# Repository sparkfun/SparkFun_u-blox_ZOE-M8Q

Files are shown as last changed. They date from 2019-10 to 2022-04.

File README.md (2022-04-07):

SparkFun u-blox ZOE-M8Q
========================================

SparkFun u-blox ZOE-M8Q (https://www.sparkfun.com/products/15193)

[*SparkFun u-blox ZOE-M8Q (GPS-15193)*](https://www.sparkfun.com/products/15193)

The ZOE-M8Q is a high quality GPS with equally impressive configurability.  We broke out the basic pins and added all the supporting circuitry to make this module even easier to use.  

Repository Contents
-------------------

* **/Documentation** - Data sheets, additional product information
* **/Hardware** - Eagle design files (.brd, .sch)
* **/Production** - Production panel files (.brd)

Documentation
--------------
* **[Installing an Arduino Library Guide](https://learn.sparkfun.com/tutorials/installing-an-arduino-library)** - Basic information on how to install an Arduino library.
* **[Library](https://github.com/sparkfun/SparkFun_u-blox_GNSS_Arduino_Library)** - Arduino Library used with the SparkFun ZOE-M8Q 
* **[Hookup Guide](https://learn.sparkfun.com/tutorials/sparkfun-gps-breakout-zoe-m8q-and-sam-m8q-hookup-guide)** - Basic hookup guide for the SparkFun ZOE-M8Q.

License Information
-------------------

This product is _**open source**_! 

Please review the LICENSE.md file for license information. 

If you have any questions or concerns on licensing, please contact technical support on our [SparkFun forums](https://forum.sparkfun.com/viewforum.php?f=152).

Distributed as-is; no warranty is given.

- Your friends at SparkFun.

_<COLLABORATION CREDIT>_

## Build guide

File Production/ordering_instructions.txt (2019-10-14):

panel size, 117x117mm
PCB thickness, 0.8mm
number of layers, 2
soldermask color, Red
silkscreen color, White
oz copper, 1oz
finish, HASL lead free
stencils, top+bottom
pcs per panel, 16
min trace width, 0.203200mm / 0.008000in
min drill size, 0.203200mm / 0.008000in

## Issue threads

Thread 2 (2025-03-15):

Confirmation of the ZOE-M8Q PPS pulse accuracy - using the SparkFun GNSSDO

PaulZC, 2025-03-15:
A customer has observed [unusual stability of the ZOE-M8Q PPS signal](https://community.sparkfun.com/t/the-configuration-of-zoe-m8q-cannot-be-permanently-saved-request-to-provide-the-latest-firmware/63843/9).

To investigate, we used the [SparkFun GNSS Disciplined Oscillator](https://www.sparkfun.com/sparkpnt-gnss-disciplined-oscillator.html) to confirm the accuracy of the PPS signal.

## Setup

[ZOE-M8Q Breakout](https://www.sparkfun.com/sparkfun-gps-breakout-zoe-m8q-qwiic.html)
3.3V power is provided via an FTDI interface cable, linking the breakout to a PC
The u.FL connector is connected to an active L1 GPS antenna with a partial (~60%) view of the sky

[SparkFun GNSSDO](https://www.sparkfun.com/sparkpnt-gnss-disciplined-oscillator.html)
Power is provided by Power-over-Ethernet
The GNSSDO has an active Fugro AtomiChron subscription
The quoted event accuracy of the mosaic-T is better than 20ns
The GNSS SMA connector is connected to an active [L1/L2/L5 antenna](https://www.sparkfun.com/gnss-multi-band-l1-l2-l5-surveying-antenna-tnc-spk6618h.html) with a good view of the sky

The ZOE PPS signal is connected to the GNSSDO EVENT_A SMA input (center pin)
ZOE GND is connected to GNSSDO GND at the EVENT_A SMA input

The [RxTools](https://www.septentrio.com/en/products/gps-gnss-receiver-software/rxtools) RxControl Expert Console ExEvent window was used to record the timing of the PPS signal. The connection was TCP/IP over Ethernet.

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

## Expected PPS Accuracy

The ZOE-M8Q datasheet quotes the accuracy of time pulse signal as better than: 30ns RMS, 60ns 99%

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

## Measured Accuracy

The ExEvent messages were logged for 1646 seconds
The ExEvent Rx TOW timestamps were extracted and converted to CSV
A simple pivot table was used to analyze the offset of the PPS events

The full CSV data is available on a [Google Sheet](https://docs.google.com/spreadsheets/d/1XdMT7Z7D9bLWwuqtR6gXf69PPPQHZF1jfgT-jtaXLxE/edit?usp=sharing)

Only five discrete pulse offsets were observed: 17ns minimum, 84ns maximum, 49.94ns was recorded for 1458 out of 1646 seconds

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

## Conclusion

We can not replicate the excessive (microsecond) pulse offsets observed by the Original Poster. The ZOE-M8Q PPS pulses appear to be completely within specification.

Closed 2025-03-15.

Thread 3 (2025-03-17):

Module configuration reverts to defaults after power outage

PaulZC, 2025-03-17:
A customer has observed that the [ZOE-M8Q reverts to the default configuration after a power outage of a few hours](https://community.sparkfun.com/t/the-configuration-of-zoe-m8q-cannot-be-permanently-saved-request-to-provide-the-latest-firmware/63843).

To replicate:

## Setup

[ZOE-M8Q Breakout](https://www.sparkfun.com/sparkfun-gps-breakout-zoe-m8q-qwiic.html)
3.3V power is provided via an FTDI interface cable, linking the breakout to a PC
The u.FL connector is connected to an active L1 GPS antenna with a partial (~60%) view of the sky

With the 3.3V FTDI serial cable connected to UART1, u-center was used to: restore the module default configuration; save the configuration; change the UART1 baud rate to 115200 baud; save the configuration.

Steps:

* UBX-CFG-CFG : "Revert to default configuration" ; Devices BBR (only) ; Send
* UBX-CFG-CFG : "Save current configuration"; Devices BBR (only); Send
* UBX-CFG-PRT : Target UART1; Baudrate 115200; Send
* Change the u-center baud rate to 115200
* UBX-CFG-CFG : "Save current configuration"; Devices BBR (only); Send

## Test 1

With the BBR battery charged and the above configuration applied, the module was disconnected from power for ~18 hours.

The FTDI cable was removed for this test. When disconnecting the 6-pin header, the header was angled so that GND was disconnected last. When reconnecting, GND was connected first.

After 18 hours, the BBR battery voltage was 2.5V

The FTDI cable was reconnected. Tera Term was opened at 115200 baud. The standard NMEA messages were observed - correctly at 115200 baud.

## Test 2

The BBR battery was recharged.

The FTDI cable was powered down, but left connected to the board.

After ~12 hours, the BBR battery voltage was 2.7V.

Power for the FTDI cable was restored and Tera Term was opened at 115200 baud.

The standard NMEA messages were not displayed. The module had reverted to the default baud rate of 9600 baud.

This appears to replicate the issue reported by the Original Poster.

## Analysis (March 17th)

From these two tests, leaving the FTDI cable attached but unpowered appears to cause the module to revert to the configuration.

The BBR battery voltage appears not to be the cause since the battery voltage was > 1.8V throughout.

## Test 3

For this test, a [Logic Pro 8](https://www.sparkfun.com/logic-pro-8-usb-logic-analyzer.html) logic analyzer is attached to the module. Five digital and analog inputs are configured, to monitor: UART1 TX; UART1 RX; VCC (3.3V); V_BATT / V_BCKP (BBR battery voltage); !RESET.

The FTDI cable and the logic analyzer are connected to the same USB hub. An in-line USB power switch allows the FTDI power to be disconnected independently.

The thesis is that having the FTDI cable attached somehow causes the module to reset.

**Note:** having the logic analyzer connected may cause V_BATT to discharge more quickly when the power is disconnected.

Here is a successful power-on where the baud rate is maintained at 115200 baud:

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

More to follow...

PaulZC, 2025-03-17:
Reading the u-blox documentation, they recommend sending "Controlled GNSS stop" (UBX-CFG-RST) before using Save-on-Shutdown (UBX-UPD-SOS_BACKUP) on modules with flash memory. The ZOE-M8Q breakout does not have flash memory, but, maybe, a controlled stop would still be beneficial?

UBX-CFG-RST is: ```0xB5, 0x62,  0x06, 0x04,  0x04, 0x00,  0x00, 0x00, 0x08, 0x00, 0x16, 0x74```

Class 0x06, ID 0x04, Length 0x0004, Hot start 0x0000, Controlled GNSS stop 0x08, Reserved 0x00

PaulZC, 2025-03-17:
After disconnecting the power for 1 hour, the baud rate is maintained

Note: V_BATT is 2.508V

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

PaulZC, 2025-03-17:
After disconnecting for another four hours, the baud rate is maintained

Note: V_BATT is 2.42V

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

PaulZC, 2025-03-18:
After disconnecting for another ~fourteen hours, the baud rate is maintained!

Note: V_BATT is 2.31V

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

PaulZC, 2025-03-18:
After disconnecting for another ~eight hours, the baud rate is maintained

Note: V_BATT is 2.30V

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

PaulZC, 2025-03-19:
After being disconnected for ~24 hours, and with the battery voltage well below 1.8V, the 115200 baud rate is still maintained:

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

I am going to give up on this. I thought I could replicate the OP's issue, but I can't...

Closed 2025-03-19.

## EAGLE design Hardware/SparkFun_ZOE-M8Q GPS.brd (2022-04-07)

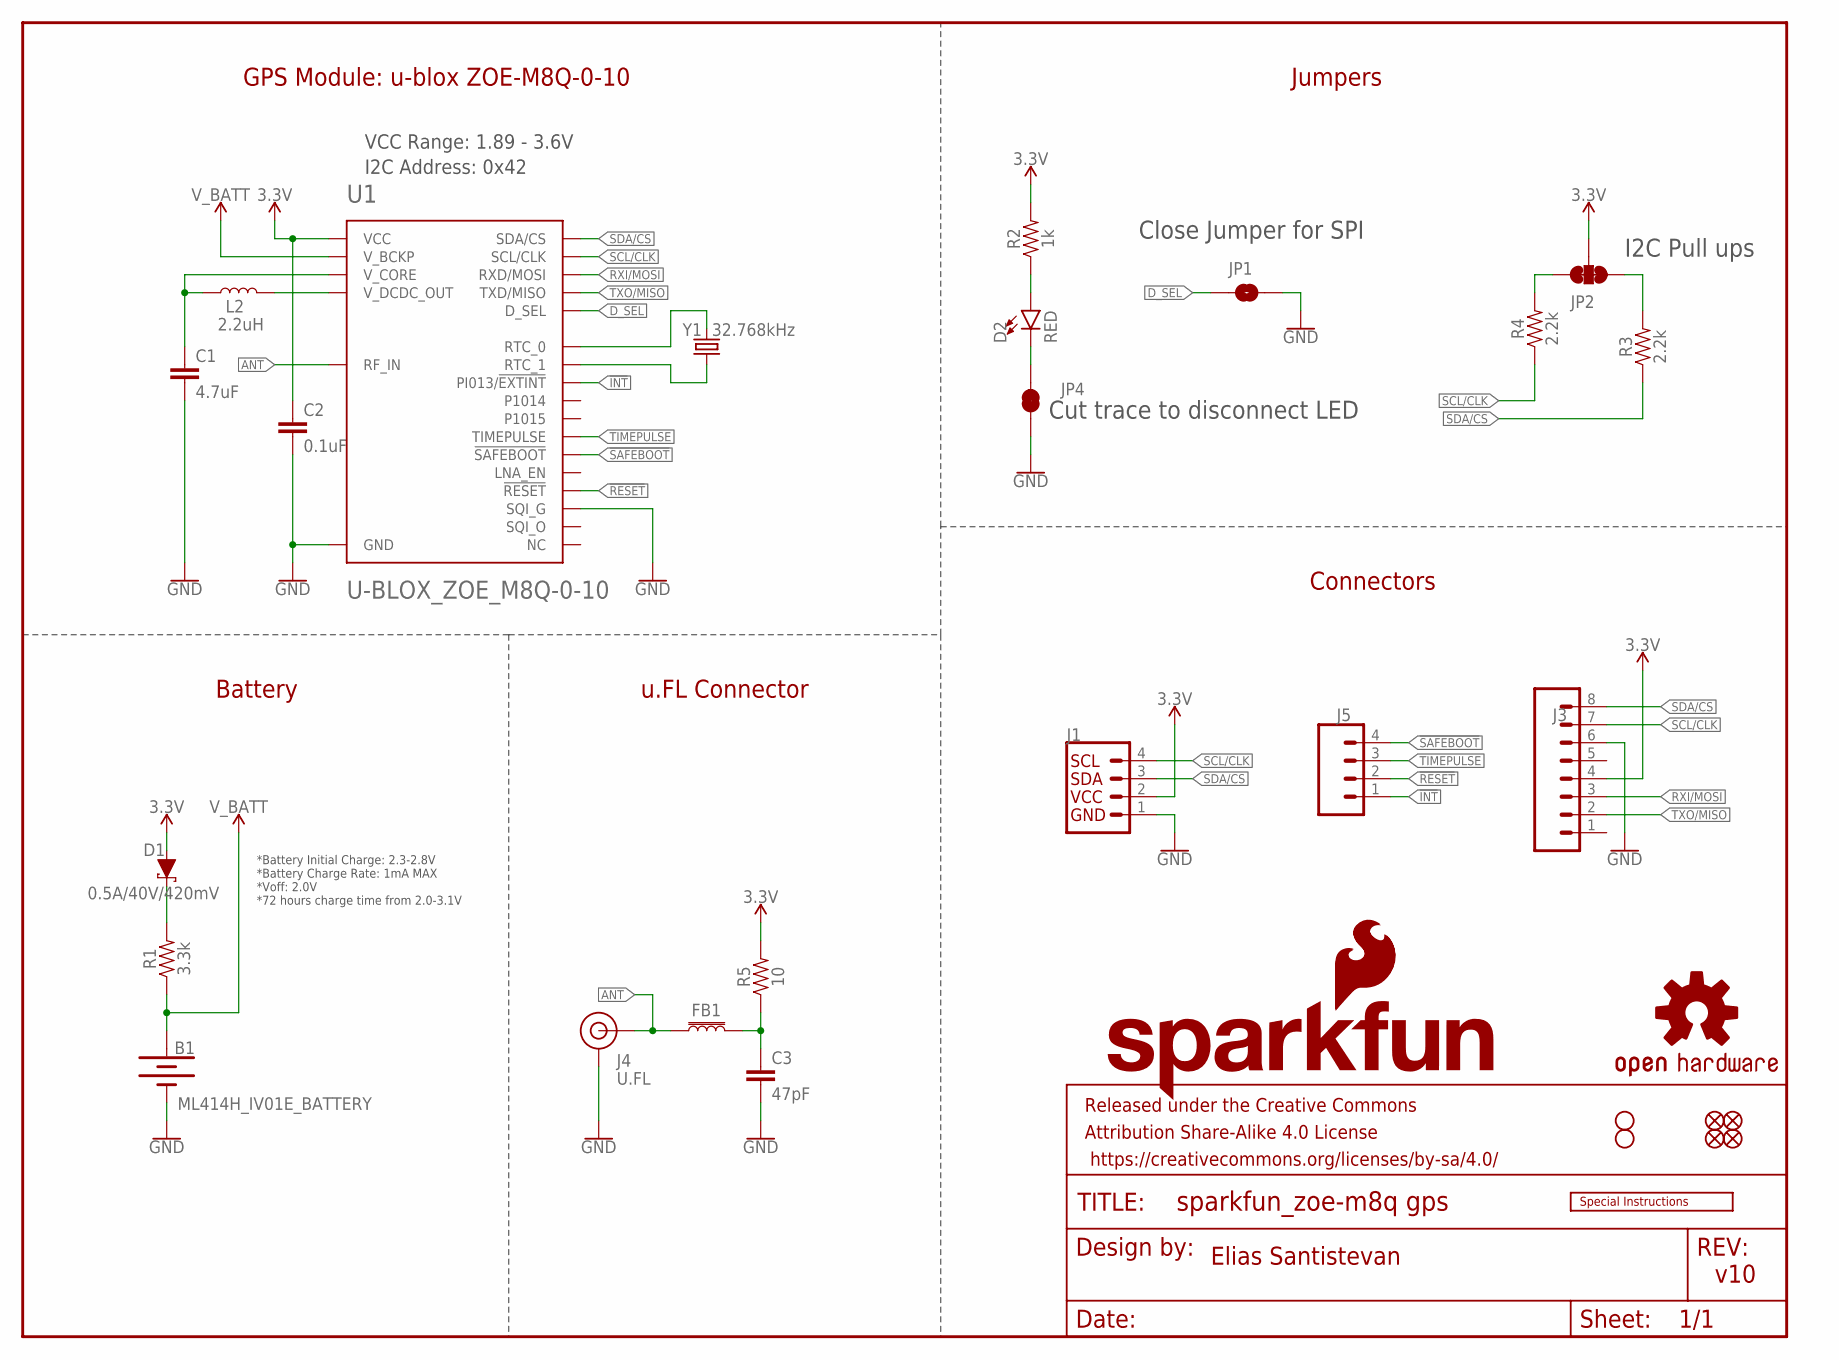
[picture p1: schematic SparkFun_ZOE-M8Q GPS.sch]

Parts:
B1: ML414H_IV01E_BATTERY; ML414H_IV01E
C1: 4.7uF; 0603
C2: 0.1uF; 0603
C3: 47pF; 0603
D1: 0.5A/40V/420mV; SOD-323
D2: RED; LED-0603
FB1: FERRITE_BEAD-120_OHM-0402; 0402
FD1, FD2, FD3, FD4: FIDUCIALUFIDUCIAL; FIDUCIAL-MICRO
FRAME1: FRAME-LETTER; CREATIVE_COMMONS
H2, H3: STAND-OFFTIGHT; STAND-OFF-TIGHT
J1: QWIIC_CONNECTORJS-1MM; JST04_1MM_RA
J3: CONN_08NO_SILK_FEMALE_PTH; 1X08_NO_SILK
J4: U.FL
J5: CONN_041X04_NO_SILK; 1X04_NO_SILK
JP1: JUMPER-SMT_2_NO_SILK; SMT-JUMPER_2_NO_SILK
JP2: JUMPER-SMT_3_2-NC_TRACE_SILK; SMT-JUMPER_3_2-NC_TRACE_SILK
JP4: JUMPER-SMT_2_NC_TRACE_SILK; SMT-JUMPER_2_NC_TRACE_SILK
L2: 2.2uH; 0806
LOGO1: SFE_LOGO_NAME_FLAME.1_INCH; SFE_LOGO_NAME_FLAME_.1
LOGO2: OSHW-LOGOS; OSHW-LOGO-S
LOGO3: SFE_LOGO_FLAME.1_INCH; SFE_LOGO_FLAME_.1
LOGO4: SPECIAL_INSTRUCTIONS-ORDERING; ORDERING_INSTRUCTIONS
R1: 3.3k; 0603
R2: 1k; 0603
R3, R4: 2.2k; 0603
R5: 10; 0603
U1: U-BLOX_ZOE_M8Q-0-10; UBLOX_ZOE_M8-0-10
Y1: 32.768kHz; CRYSTAL-SMD-3.2X1.5MM

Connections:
3.3V: C2.1, D1.A, J1.2, J3.4, JP2.2, R2.2, R5.2, U1.24 (VCC), U1.25 (VCC)
!INT: J5.1, U1.43 (PI013/!EXTINT)
!RESET: J5.2, U1.20 (!RESET)
!SAFEBOOT: J5.4, U1.34 (!SAFEBOOT)
ANT: FB1.1, J4.FEED (SIGNAL), U1.4 (RF_IN)
D_SEL: JP1.1, U1.48 (D_SEL)
GND: B1.-, C1.2, C2.2, C3.2, J1.1, J3.6, J4.1 (GND), J4.2 (GND), JP1.2, JP4.1, U1.1 (GND), U1.3 (GND), U1.5 (GND), U1.7 (GND), U1.8 (GND), U1.9 (GND), U1.10 (GND), U1.11 (GND), U1.12 (GND), U1.17 (GND), U1.23 (GND), U1.29 (SQI_G), U1.31 (SQI_G), U1.37 (GND), U1.38 (GND), U1.39 (GND), U1.40 (GND), U1.41 (GND), U1.44 (GND), U1.46 (SQI_G), U1.47 (SQI_G), U1.49 (GND)
unnamed: JP2.1, R3.2
unnamed: D1.C, R1.2
unnamed: JP2.3, R4.2
unnamed: D2.A, R2.1
unnamed: C1.1, L2.1, U1.27 (V_CORE)
unnamed: L2.2, U1.26 (V_DCDC_OUT)
unnamed: D2.C, JP4.2
unnamed: C3.1, FB1.2, R5.1
unnamed: U1.18 (RTC_0), Y1.P$2 (2)
unnamed: U1.19 (RTC_1), Y1.P$1 (1)
RXI/MOSI: J3.3, U1.22 (RXD/MOSI)
SCL/CLK: J1.4, J3.7, R4.1, U1.32 (SCL/CLK)
SDA/CS: J1.3, J3.8, R3.1, U1.2 (SDA/CS)
TIMEPULSE: J5.3, U1.33 (TIMEPULSE)
TXO/MISO: J3.2, U1.21 (TXD/MISO)
V_BATT: B1.+, R1.1, U1.16 (V_BCKP)

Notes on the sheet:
v10
Elias Santistevan
GPS Module: u-blox ZOE-M8Q-0-10
Battery
Connectors
Jumpers
Close Jumper for SPI
I2C Pull ups
Cut trace to disconnect LED
u.FL Connector
*Battery Initial Charge: 2.3-2.8V *Battery Charge Rate: 1mA MAX *Voff: 2.0V *72 hours charge time from 2.0-3.1V
VCC Range: 1.89 - 3.6V
I2C Address: 0x42

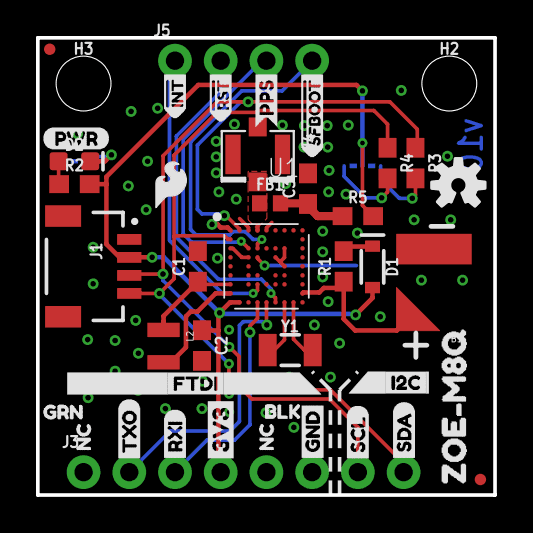
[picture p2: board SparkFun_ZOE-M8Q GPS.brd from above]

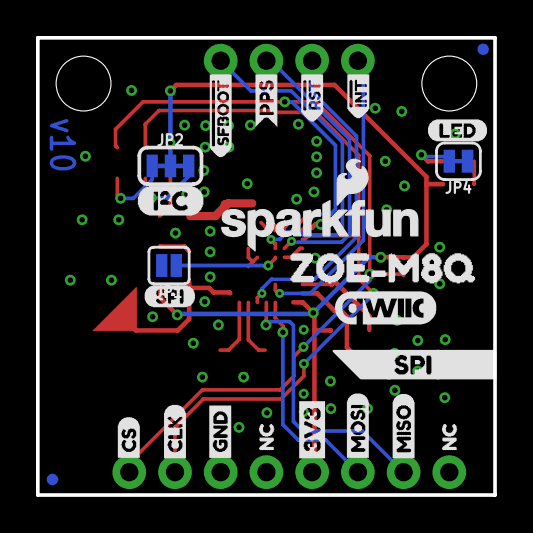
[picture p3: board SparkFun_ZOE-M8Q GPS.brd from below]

Board: 2 copper layers, 25.4 x 25.4 mm, 69 parts (24 on the bottom side), 23 nets.

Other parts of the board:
U$1, U$10: 3V3-03
U$2: SDA0
U$3: SCL0
U$4, U$7: GND0
U$5: CS0
U$6: MISO0
U$8: CLK0
U$9, U$17: SPI0
U$11, U$18: #INT0
U$12, U$21: #RST0
U$13, U$23: PPS0
U$14, U$24: #SFBOOT0
U$15: TXO0
U$16, U$30: ZOE#M8Q0
U$19: RXI0
U$20: BLK0
U$22, U$33, U$34, U$35: NC0
U$25: LED0
U$26: PWR-()-03
U$27: MOSI0
U$28: FTDI0
U$29: I2C0
U$31: GRN0
U$32: I_SUPER2_C-()-04
U$36: QWIIC_COPYRIGHT_SMALL

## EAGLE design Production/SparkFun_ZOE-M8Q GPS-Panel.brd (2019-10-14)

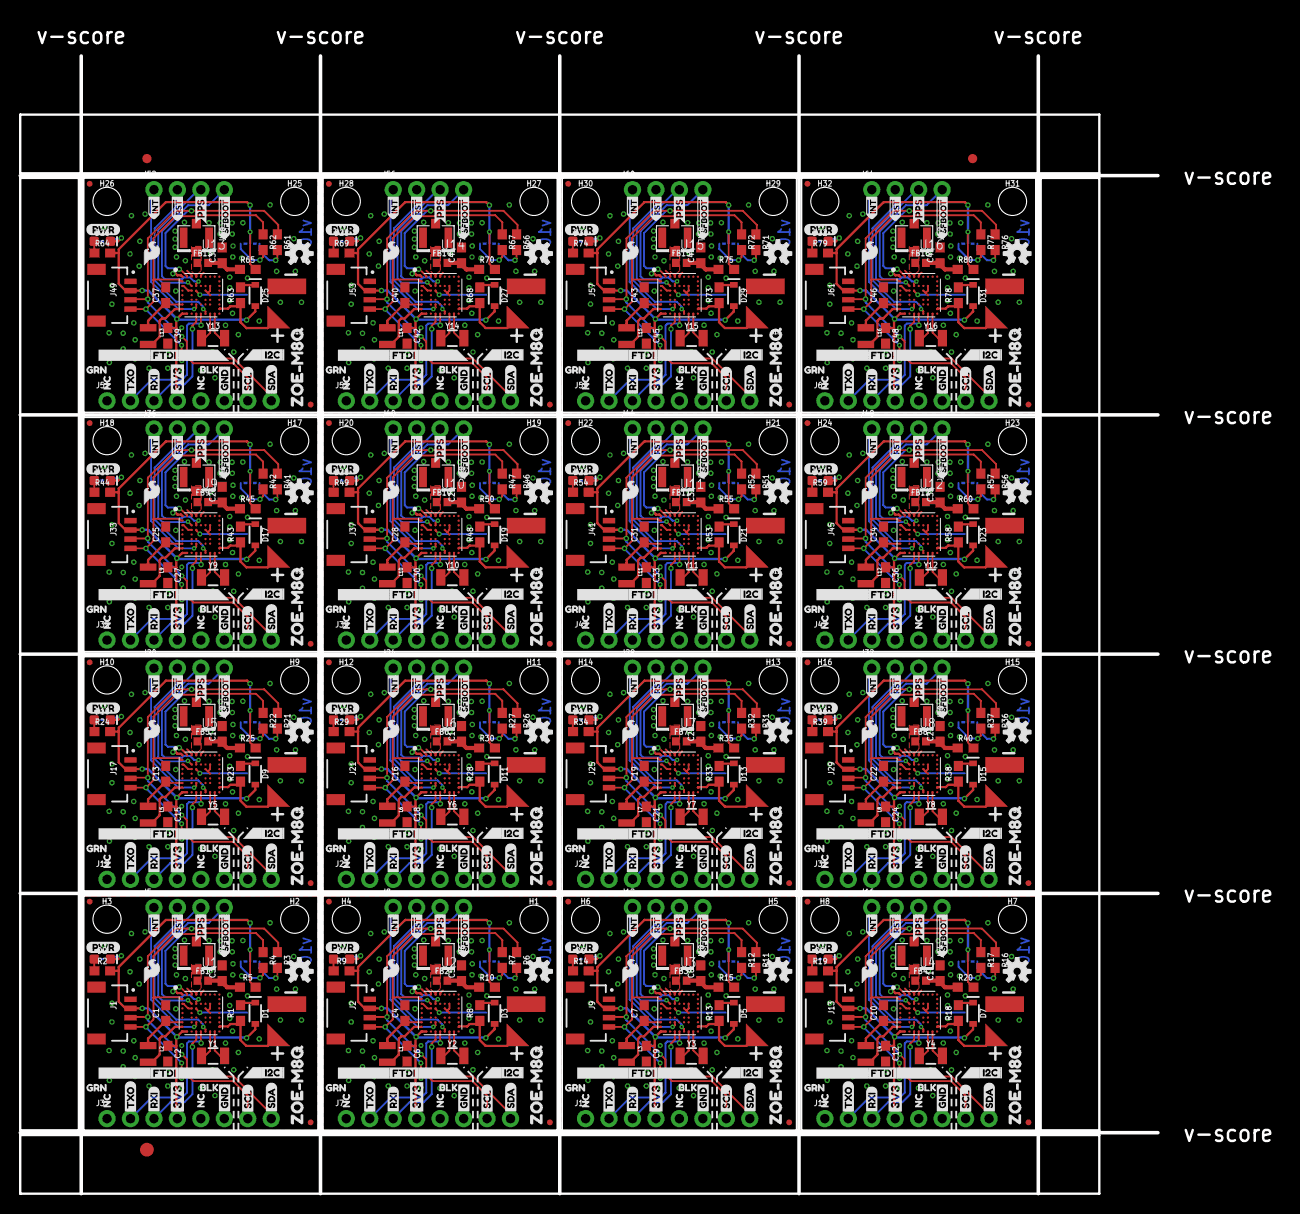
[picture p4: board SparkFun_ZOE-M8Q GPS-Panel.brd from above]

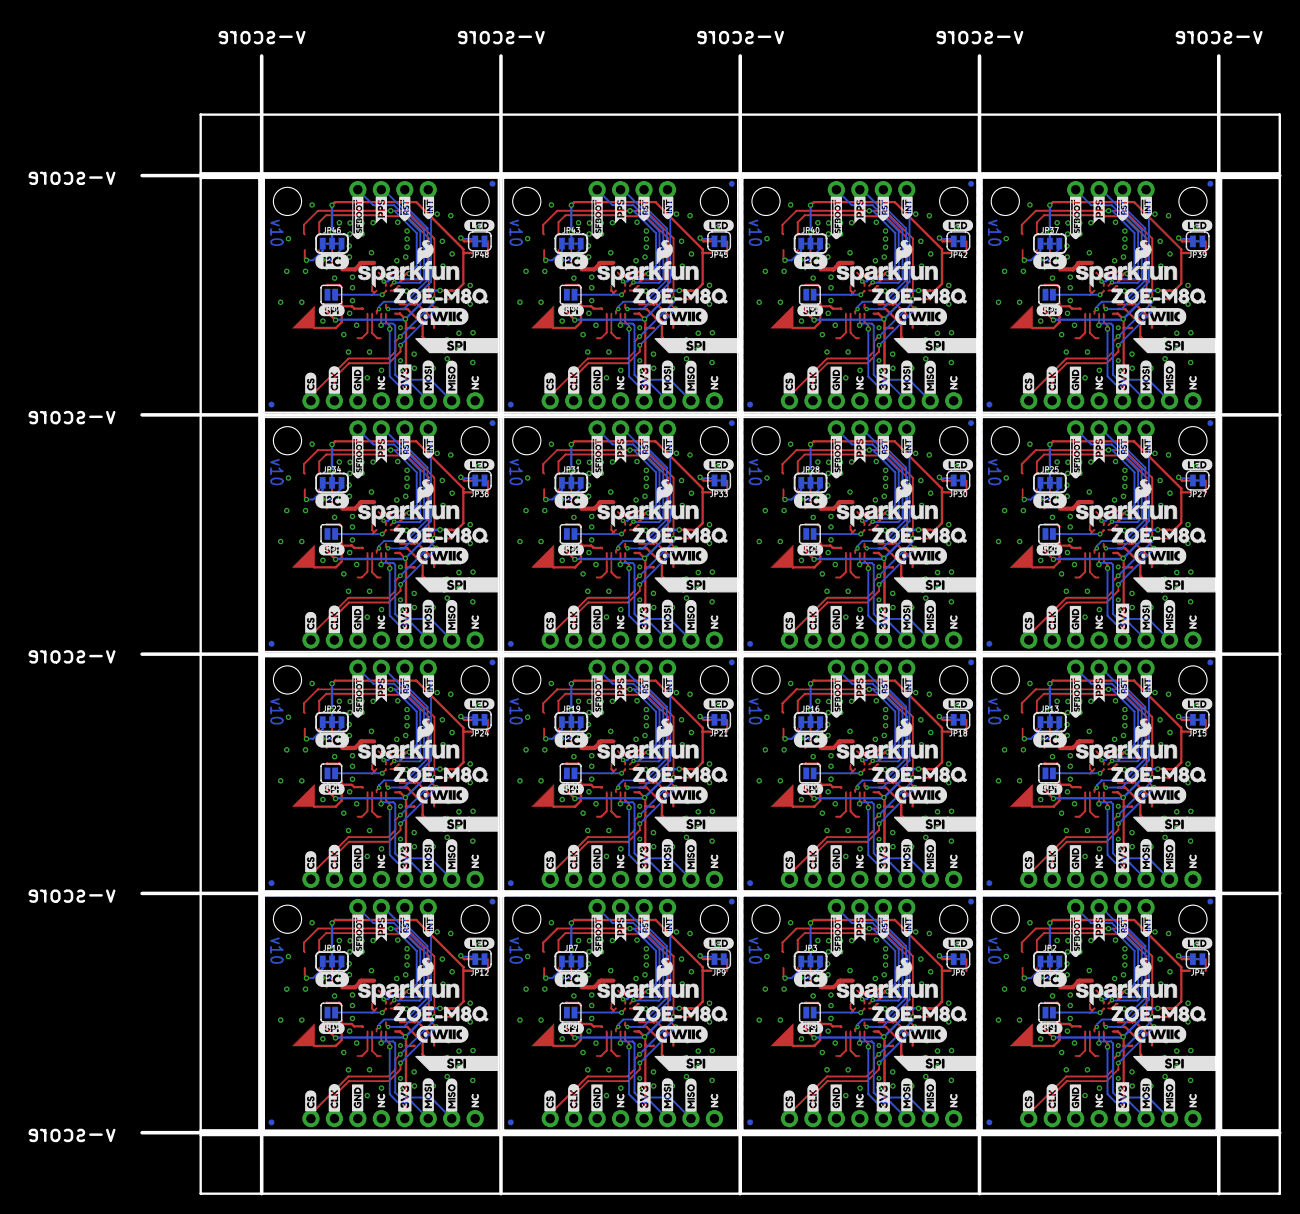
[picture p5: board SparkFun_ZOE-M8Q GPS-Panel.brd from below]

Board: 2 copper layers, 123.2 x 123.2 mm, 1075 parts (384 on the bottom side), 368 nets.

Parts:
B1, B2, B3, B4, B5, B6, B7, B8, B9, B10, B11, B12, B13, B14, B15, B16: ML414H_IV01E_BATTERY; ML414H_IV01E
C1, C4, C7, C10, C13, C16, C19, C22, C25, C28, C31, C34, C37, C40, C43, C46: 4.7uF; 0603
C2, C6, C9, C12, C15, C18, C21, C24, C27, C30, C33, C36, C39, C42, C45, C48: 0.1uF; 0603
C3, C5, C8, C11, C14, C17, C20, C23, C26, C29, C32, C35, C38, C41, C44, C47: 47pF; 0603
D1, D3, D5, D7, D9, D11, D13, D15, D17, D19, D21, D23, D25, D27, D29, D31: 0.5A/40V/420mV; SOD-323
D2, D4, D6, D8, D10, D12, D14, D16, D18, D20, D22, D24, D26, D28, D30, D32: RED; LED-0603
E$1, E$2: FIDUCIAL-1X2
E$3: FIDUCIAL-1.5X3
FB1, FB2, FB3, FB4, FB5, FB6, FB7, FB8, FB9, FB10, FB11, FB12, FB13, FB14, FB15, FB16: FERRITE_BEAD-120_OHM-0402; 0402
FD1, FD2, FD3, FD4, FD5, FD6, FD7, FD8, FD9, FD10, FD11, FD12, FD13, FD14, FD15, FD16, FD17, FD18, FD19, FD20, FD21, FD22, FD23, FD24, FD25, FD26, FD27, FD28, FD29, FD30, FD31, FD32, FD33, FD34, FD35, FD36, FD37, FD38, FD39, FD40, FD41, FD42, FD43, FD44, FD45, FD46, FD47, FD48, FD49, FD50, FD51, FD52, FD53, FD54, FD55, FD56, FD57, FD58, FD59, FD60, FD61, FD62, FD63, FD64: FIDUCIALUFIDUCIAL; FIDUCIAL-MICRO
H1, H2, H3, H4, H5, H6, H7, H8, H9, H10, H11, H12, H13, H14, H15, H16, H17, H18, H19, H20, H21, H22, H23, H24, H25, H26, H27, H28, H29, H30, H31, H32: STAND-OFFTIGHT; STAND-OFF-TIGHT
J1, J2, J9, J13, J17, J21, J25, J29, J33, J37, J41, J45, J49, J53, J57, J61: JST04_1MM_RA
J3, J7, J11, J15, J19, J23, J27, J31, J35, J39, J43, J47, J51, J55, J59, J63: 1X08_NO_SILK
J4, J6, J10, J14, J18, J22, J26, J30, J34, J38, J42, J46, J50, J54, J58, J62: U.FL
J5, J8, J12, J16, J20, J24, J28, J32, J36, J40, J44, J48, J52, J56, J60, J64: 1X04_NO_SILK
JP1, JP5, JP8, JP11, JP14, JP17, JP20, JP23, JP26, JP29, JP32, JP35, JP38, JP41, JP44, JP47: JUMPER-SMT_2_NO_SILK; SMT-JUMPER_2_NO_SILK
JP2, JP3, JP7, JP10, JP13, JP16, JP19, JP22, JP25, JP28, JP31, JP34, JP37, JP40, JP43, JP46: JUMPER-SMT_3_2-NC_TRACE_SILK; SMT-JUMPER_3_2-NC_TRACE_SILK
JP4, JP6, JP9, JP12, JP15, JP18, JP21, JP24, JP27, JP30, JP33, JP36, JP39, JP42, JP45, JP48: JUMPER-SMT_2_NC_TRACE_SILK; SMT-JUMPER_2_NC_TRACE_SILK
L1, L2, L3, L4, L5, L6, L7, L8, L9, L10, L11, L12, L13, L14, L15, L16: 2.2uH; 0806
LOGO1, LOGO4, LOGO7, LOGO10, LOGO13, LOGO16, LOGO19, LOGO22, LOGO25, LOGO28, LOGO31, LOGO34, LOGO37, LOGO40, LOGO43, LOGO46: SFE_LOGO_NAME_FLAME.1_INCH; SFE_LOGO_NAME_FLAME_.1
LOGO2, LOGO5, LOGO8, LOGO11, LOGO14, LOGO17, LOGO20, LOGO23, LOGO26, LOGO29, LOGO32, LOGO35, LOGO38, LOGO41, LOGO44, LOGO47: OSHW-LOGOS; OSHW-LOGO-S
LOGO3, LOGO6, LOGO9, LOGO12, LOGO15, LOGO18, LOGO21, LOGO24, LOGO27, LOGO30, LOGO33, LOGO36, LOGO39, LOGO42, LOGO45, LOGO48: SFE_LOGO_FLAME.1_INCH; SFE_LOGO_FLAME_.1
R1, R8, R13, R18, R23, R28, R33, R38, R43, R48, R53, R58, R63, R68, R73, R78: 3.3k; 0603
R2, R9, R14, R19, R24, R29, R34, R39, R44, R49, R54, R59, R64, R69, R74, R79: 1k; 0603
R3, R4, R6, R7, R11, R12, R16, R17, R21, R22, R26, R27, R31, R32, R36, R37, R41, R42, R46, R47, R51, R52, R56, R57, R61, R62, R66, R67, R71, R72, R76, R77: 2.2k; 0603
R5, R10, R15, R20, R25, R30, R35, R40, R45, R50, R55, R60, R65, R70, R75, R80: 10; 0603
U1, U2, U3, U4, U5, U6, U7, U8, U9, U10, U11, U12, U13, U14, U15, U16: UBLOX_ZOE_M8-0-10
U$1, U$10, U$37, U$43, U$73, U$79, U$109, U$115, U$145, U$151, U$181, U$187, U$217, U$223, U$253, U$259, U$289, U$295, U$325, U$331, U$361, U$367, U$397, U$403, U$433, U$439, U$469, U$475, U$505, U$511, U$541, U$547: 3V3-03
U$2, U$38, U$74, U$110, U$146, U$182, U$218, U$254, U$290, U$326, U$362, U$398, U$434, U$470, U$506, U$542: SDA0
U$3, U$39, U$75, U$111, U$147, U$183, U$219, U$255, U$291, U$327, U$363, U$399, U$435, U$471, U$507, U$543: SCL0
U$4, U$7, U$40, U$41, U$76, U$77, U$112, U$113, U$148, U$149, U$184, U$185, U$220, U$221, U$256, U$257, U$292, U$293, U$328, U$329, U$364, U$365, U$400, U$401, U$436, U$437, U$472, U$473, U$508, U$509, U$544, U$545: GND0
U$5, U$56, U$92, U$128, U$164, U$200, U$236, U$272, U$308, U$344, U$380, U$416, U$452, U$488, U$524, U$560: CS0
U$6, U$54, U$90, U$126, U$162, U$198, U$234, U$270, U$306, U$342, U$378, U$414, U$450, U$486, U$522, U$558: MISO0
U$8, U$42, U$78, U$114, U$150, U$186, U$222, U$258, U$294, U$330, U$366, U$402, U$438, U$474, U$510, U$546: CLK0
U$9, U$17, U$45, U$57, U$81, U$93, U$117, U$129, U$153, U$165, U$189, U$201, U$225, U$237, U$261, U$273, U$297, U$309, U$333, U$345, U$369, U$381, U$405, U$417, U$441, U$453, U$477, U$489, U$513, U$525, U$549, U$561: SPI0
U$11, U$18, U$64, U$65, U$100, U$101, U$136, U$137, U$172, U$173, U$208, U$209, U$244, U$245, U$280, U$281, U$316, U$317, U$352, U$353, U$388, U$389, U$424, U$425, U$460, U$461, U$496, U$497, U$532, U$533, U$568, U$569: #INT0
U$12, U$21, U$66, U$67, U$102, U$103, U$138, U$139, U$174, U$175, U$210, U$211, U$246, U$247, U$282, U$283, U$318, U$319, U$354, U$355, U$390, U$391, U$426, U$427, U$462, U$463, U$498, U$499, U$534, U$535, U$570, U$571: #RST0
U$13, U$23, U$46, U$47, U$82, U$83, U$118, U$119, U$154, U$155, U$190, U$191, U$226, U$227, U$262, U$263, U$298, U$299, U$334, U$335, U$370, U$371, U$406, U$407, U$442, U$443, U$478, U$479, U$514, U$515, U$550, U$551: PPS0
U$14, U$24, U$48, U$49, U$84, U$85, U$120, U$121, U$156, U$157, U$192, U$193, U$228, U$229, U$264, U$265, U$300, U$301, U$336, U$337, U$372, U$373, U$408, U$409, U$444, U$445, U$480, U$481, U$516, U$517, U$552, U$553: #SFBOOT0
U$15, U$52, U$88, U$124, U$160, U$196, U$232, U$268, U$304, U$340, U$376, U$412, U$448, U$484, U$520, U$556: TXO0
U$16, U$30, U$44, U$60, U$80, U$96, U$116, U$132, U$152, U$168, U$188, U$204, U$224, U$240, U$260, U$276, U$296, U$312, U$332, U$348, U$368, U$384, U$404, U$420, U$440, U$456, U$476, U$492, U$512, U$528, U$548, U$564: ZOE#M8Q0
U$19, U$53, U$89, U$125, U$161, U$197, U$233, U$269, U$305, U$341, U$377, U$413, U$449, U$485, U$521, U$557: RXI0
U$20, U$61, U$97, U$133, U$169, U$205, U$241, U$277, U$313, U$349, U$385, U$421, U$457, U$493, U$529, U$565: BLK0
U$22, U$33, U$34, U$35, U$68, U$69, U$70, U$71, U$104, U$105, U$106, U$107, U$140, U$141, U$142, U$143, U$176, U$177, U$178, U$179, U$212, U$213, U$214, U$215, U$248, U$249, U$250, U$251, U$284, U$285, U$286, U$287, U$320, U$321, U$322, U$323, U$356, U$357, U$358, U$359, U$392, U$393, U$394, U$395, U$428, U$429, U$430, U$431, U$464, U$465, U$466, U$467, U$500, U$501, U$502, U$503, U$536, U$537, U$538, U$539, U$572, U$573, U$574, U$575: NC0
U$25, U$50, U$86, U$122, U$158, U$194, U$230, U$266, U$302, U$338, U$374, U$410, U$446, U$482, U$518, U$554: LED0
U$26, U$51, U$87, U$123, U$159, U$195, U$231, U$267, U$303, U$339, U$375, U$411, U$447, U$483, U$519, U$555: PWR-()-03
U$27, U$55, U$91, U$127, U$163, U$199, U$235, U$271, U$307, U$343, U$379, U$415, U$451, U$487, U$523, U$559: MOSI0
U$28, U$58, U$94, U$130, U$166, U$202, U$238, U$274, U$310, U$346, U$382, U$418, U$454, U$490, U$526, U$562: FTDI0
U$29, U$59, U$95, U$131, U$167, U$203, U$239, U$275, U$311, U$347, U$383, U$419, U$455, U$491, U$527, U$563: I2C0
U$31, U$62, U$98, U$134, U$170, U$206, U$242, U$278, U$314, U$350, U$386, U$422, U$458, U$494, U$530, U$566: GRN0
U$32, U$63, U$99, U$135, U$171, U$207, U$243, U$279, U$315, U$351, U$387, U$423, U$459, U$495, U$531, U$567: I_SUPER2_C-()-04
U$36, U$72, U$108, U$144, U$180, U$216, U$252, U$288, U$324, U$360, U$396, U$432, U$468, U$504, U$540, U$576: QWIIC_COPYRIGHT_SMALL
Y1, Y2, Y3, Y4, Y5, Y6, Y7, Y8, Y9, Y10, Y11, Y12, Y13, Y14, Y15, Y16: 32.768kHz; CRYSTAL-SMD-3.2X1.5MM

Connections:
3.3V: C2.1, D1.A, J1.2, J3.4, JP2.2, R2.2, R5.2, U1.24, U1.25
3.3V1: C6.1, D3.A, J2.2, J7.4, JP3.2, R9.2, R10.2, U2.24, U2.25
3.3V2: C9.1, D5.A, J9.2, J11.4, JP7.2, R14.2, R15.2, U3.24, U3.25
3.3V3: C12.1, D7.A, J13.2, J15.4, JP10.2, R19.2, R20.2, U4.24, U4.25
3.3V4: C15.1, D9.A, J17.2, J19.4, JP13.2, R24.2, R25.2, U5.24, U5.25
3.3V5: C18.1, D11.A, J21.2, J23.4, JP16.2, R29.2, R30.2, U6.24, U6.25
3.3V6: C21.1, D13.A, J25.2, J27.4, JP19.2, R34.2, R35.2, U7.24, U7.25
3.3V7: C24.1, D15.A, J29.2, J31.4, JP22.2, R39.2, R40.2, U8.24, U8.25
3.3V8: C27.1, D17.A, J33.2, J35.4, JP25.2, R44.2, R45.2, U9.24, U9.25
3.3V9: C30.1, D19.A, J37.2, J39.4, JP28.2, R49.2, R50.2, U10.24, U10.25
3.3V10: C33.1, D21.A, J41.2, J43.4, JP31.2, R54.2, R55.2, U11.24, U11.25
3.3V11: C36.1, D23.A, J45.2, J47.4, JP34.2, R59.2, R60.2, U12.24, U12.25
3.3V12: C39.1, D25.A, J49.2, J51.4, JP37.2, R64.2, R65.2, U13.24, U13.25
3.3V13: C42.1, D27.A, J53.2, J55.4, JP40.2, R69.2, R70.2, U14.24, U14.25
3.3V14: C45.1, D29.A, J57.2, J59.4, JP43.2, R74.2, R75.2, U15.24, U15.25
3.3V15: C48.1, D31.A, J61.2, J63.4, JP46.2, R79.2, R80.2, U16.24, U16.25
!INT: J5.1, U1.43
!INT1: J8.1, U2.43
!INT2: J12.1, U3.43
!INT3: J16.1, U4.43
!INT4: J20.1, U5.43
!INT5: J24.1, U6.43
!INT6: J28.1, U7.43
!INT7: J32.1, U8.43
!INT8: J36.1, U9.43
!INT9: J40.1, U10.43
!INT10: J44.1, U11.43
!INT11: J48.1, U12.43
!INT12: J52.1, U13.43
!INT13: J56.1, U14.43
!INT14: J60.1, U15.43
!INT15: J64.1, U16.43
!RESET: J5.2, U1.20
!RESET1: J8.2, U2.20
!RESET2: J12.2, U3.20
!RESET3: J16.2, U4.20
!RESET4: J20.2, U5.20
!RESET5: J24.2, U6.20
!RESET6: J28.2, U7.20
!RESET7: J32.2, U8.20
!RESET8: J36.2, U9.20
!RESET9: J40.2, U10.20
!RESET10: J44.2, U11.20
!RESET11: J48.2, U12.20
!RESET12: J52.2, U13.20
!RESET13: J56.2, U14.20
!RESET14: J60.2, U15.20
!RESET15: J64.2, U16.20
!SAFEBOOT: J5.4, U1.34
!SAFEBOOT1: J8.4, U2.34
!SAFEBOOT2: J12.4, U3.34
!SAFEBOOT3: J16.4, U4.34
!SAFEBOOT4: J20.4, U5.34
!SAFEBOOT5: J24.4, U6.34
!SAFEBOOT6: J28.4, U7.34
!SAFEBOOT7: J32.4, U8.34
!SAFEBOOT8: J36.4, U9.34
!SAFEBOOT9: J40.4, U10.34
!SAFEBOOT10: J44.4, U11.34
!SAFEBOOT11: J48.4, U12.34
!SAFEBOOT12: J52.4, U13.34
!SAFEBOOT13: J56.4, U14.34
!SAFEBOOT14: J60.4, U15.34
!SAFEBOOT15: J64.4, U16.34
ANT: FB1.1, J4.FEED, U1.4
ANT1: FB2.1, J6.FEED, U2.4
ANT2: FB3.1, J10.FEED, U3.4
ANT3: FB4.1, J14.FEED, U4.4
ANT4: FB5.1, J18.FEED, U5.4
ANT5: FB6.1, J22.FEED, U6.4
ANT6: FB7.1, J26.FEED, U7.4
ANT7: FB8.1, J30.FEED, U8.4
ANT8: FB9.1, J34.FEED, U9.4
ANT9: FB10.1, J38.FEED, U10.4
ANT10: FB11.1, J42.FEED, U11.4
ANT11: FB12.1, J46.FEED, U12.4
ANT12: FB13.1, J50.FEED, U13.4
ANT13: FB14.1, J54.FEED, U14.4
ANT14: FB15.1, J58.FEED, U15.4
ANT15: FB16.1, J62.FEED, U16.4
D_SEL: JP1.1, U1.48
D_SEL1: JP5.1, U2.48
D_SEL2: JP8.1, U3.48
D_SEL3: JP11.1, U4.48
D_SEL4: JP14.1, U5.48
D_SEL5: JP17.1, U6.48
D_SEL6: JP20.1, U7.48
D_SEL7: JP23.1, U8.48
D_SEL8: JP26.1, U9.48
D_SEL9: JP29.1, U10.48
D_SEL10: JP32.1, U11.48
D_SEL11: JP35.1, U12.48
D_SEL12: JP38.1, U13.48
D_SEL13: JP41.1, U14.48
D_SEL14: JP44.1, U15.48
D_SEL15: JP47.1, U16.48
GND: B1.-, C1.2, C2.2, C3.2, J1.1, J3.6, J4.1, J4.2, JP1.2, JP4.1, U1.1, U1.3, U1.5, U1.7, U1.8, U1.9, U1.10, U1.11, U1.12, U1.17, U1.23, U1.29, U1.31, U1.37, U1.38, U1.39, U1.40, U1.41, U1.44, U1.46, U1.47, U1.49
GND1: B2.-, C4.2, C5.2, C6.2, J2.1, J6.1, J6.2, J7.6, JP5.2, JP6.1, U2.1, U2.3, U2.5, U2.7, U2.8, U2.9, U2.10, U2.11, U2.12, U2.17, U2.23, U2.29, U2.31, U2.37, U2.38, U2.39, U2.40, U2.41, U2.44, U2.46, U2.47, U2.49
GND2: B3.-, C7.2, C8.2, C9.2, J9.1, J10.1, J10.2, J11.6, JP8.2, JP9.1, U3.1, U3.3, U3.5, U3.7, U3.8, U3.9, U3.10, U3.11, U3.12, U3.17, U3.23, U3.29, U3.31, U3.37, U3.38, U3.39, U3.40, U3.41, U3.44, U3.46, U3.47, U3.49
GND3: B4.-, C10.2, C11.2, C12.2, J13.1, J14.1, J14.2, J15.6, JP11.2, JP12.1, U4.1, U4.3, U4.5, U4.7, U4.8, U4.9, U4.10, U4.11, U4.12, U4.17, U4.23, U4.29, U4.31, U4.37, U4.38, U4.39, U4.40, U4.41, U4.44, U4.46, U4.47, U4.49
GND4: B5.-, C13.2, C14.2, C15.2, J17.1, J18.1, J18.2, J19.6, JP14.2, JP15.1, U5.1, U5.3, U5.5, U5.7, U5.8, U5.9, U5.10, U5.11, U5.12, U5.17, U5.23, U5.29, U5.31, U5.37, U5.38, U5.39, U5.40, U5.41, U5.44, U5.46, U5.47, U5.49
GND5: B6.-, C16.2, C17.2, C18.2, J21.1, J22.1, J22.2, J23.6, JP17.2, JP18.1, U6.1, U6.3, U6.5, U6.7, U6.8, U6.9, U6.10, U6.11, U6.12, U6.17, U6.23, U6.29, U6.31, U6.37, U6.38, U6.39, U6.40, U6.41, U6.44, U6.46, U6.47, U6.49
GND6: B7.-, C19.2, C20.2, C21.2, J25.1, J26.1, J26.2, J27.6, JP20.2, JP21.1, U7.1, U7.3, U7.5, U7.7, U7.8, U7.9, U7.10, U7.11, U7.12, U7.17, U7.23, U7.29, U7.31, U7.37, U7.38, U7.39, U7.40, U7.41, U7.44, U7.46, U7.47, U7.49
GND7: B8.-, C22.2, C23.2, C24.2, J29.1, J30.1, J30.2, J31.6, JP23.2, JP24.1, U8.1, U8.3, U8.5, U8.7, U8.8, U8.9, U8.10, U8.11, U8.12, U8.17, U8.23, U8.29, U8.31, U8.37, U8.38, U8.39, U8.40, U8.41, U8.44, U8.46, U8.47, U8.49
GND8: B9.-, C25.2, C26.2, C27.2, J33.1, J34.1, J34.2, J35.6, JP26.2, JP27.1, U9.1, U9.3, U9.5, U9.7, U9.8, U9.9, U9.10, U9.11, U9.12, U9.17, U9.23, U9.29, U9.31, U9.37, U9.38, U9.39, U9.40, U9.41, U9.44, U9.46, U9.47, U9.49
GND9: B10.-, C28.2, C29.2, C30.2, J37.1, J38.1, J38.2, J39.6, JP29.2, JP30.1, U10.1, U10.3, U10.5, U10.7, U10.8, U10.9, U10.10, U10.11, U10.12, U10.17, U10.23, U10.29, U10.31, U10.37, U10.38, U10.39, U10.40, U10.41, U10.44, U10.46, U10.47, U10.49
GND10: B11.-, C31.2, C32.2, C33.2, J41.1, J42.1, J42.2, J43.6, JP32.2, JP33.1, U11.1, U11.3, U11.5, U11.7, U11.8, U11.9, U11.10, U11.11, U11.12, U11.17, U11.23, U11.29, U11.31, U11.37, U11.38, U11.39, U11.40, U11.41, U11.44, U11.46, U11.47, U11.49
GND11: B12.-, C34.2, C35.2, C36.2, J45.1, J46.1, J46.2, J47.6, JP35.2, JP36.1, U12.1, U12.3, U12.5, U12.7, U12.8, U12.9, U12.10, U12.11, U12.12, U12.17, U12.23, U12.29, U12.31, U12.37, U12.38, U12.39, U12.40, U12.41, U12.44, U12.46, U12.47, U12.49
GND12: B13.-, C37.2, C38.2, C39.2, J49.1, J50.1, J50.2, J51.6, JP38.2, JP39.1, U13.1, U13.3, U13.5, U13.7, U13.8, U13.9, U13.10, U13.11, U13.12, U13.17, U13.23, U13.29, U13.31, U13.37, U13.38, U13.39, U13.40, U13.41, U13.44, U13.46, U13.47, U13.49
GND13: B14.-, C40.2, C41.2, C42.2, J53.1, J54.1, J54.2, J55.6, JP41.2, JP42.1, U14.1, U14.3, U14.5, U14.7, U14.8, U14.9, U14.10, U14.11, U14.12, U14.17, U14.23, U14.29, U14.31, U14.37, U14.38, U14.39, U14.40, U14.41, U14.44, U14.46, U14.47, U14.49
GND14: B15.-, C43.2, C44.2, C45.2, J57.1, J58.1, J58.2, J59.6, JP44.2, JP45.1, U15.1, U15.3, U15.5, U15.7, U15.8, U15.9, U15.10, U15.11, U15.12, U15.17, U15.23, U15.29, U15.31, U15.37, U15.38, U15.39, U15.40, U15.41, U15.44, U15.46, U15.47, U15.49
GND15: B16.-, C46.2, C47.2, C48.2, J61.1, J62.1, J62.2, J63.6, JP47.2, JP48.1, U16.1, U16.3, U16.5, U16.7, U16.8, U16.9, U16.10, U16.11, U16.12, U16.17, U16.23, U16.29, U16.31, U16.37, U16.38, U16.39, U16.40, U16.41, U16.44, U16.46, U16.47, U16.49
unnamed: JP2.1, R3.2
unnamed: D1.C, R1.2
unnamed: JP2.3, R4.2
unnamed: D2.A, R2.1
unnamed: L1.2, U2.26
unnamed: C1.1, L2.1, U1.27
unnamed: L2.2, U1.26
unnamed: D2.C, JP4.2
unnamed: C3.1, FB1.2, R5.1
unnamed: C4.1, L1.1, U2.27
unnamed: U2.18, Y2.P$2
unnamed: U2.19, Y2.P$1
unnamed: U1.18, Y1.P$2
unnamed: D3.C, R8.2
unnamed: U1.19, Y1.P$1
unnamed: JP3.1, R6.2
unnamed: JP3.3, R7.2
unnamed: D4.A, R9.1
unnamed: D4.C, JP6.2
unnamed: C5.1, FB2.2, R10.1
unnamed: L3.2, U3.26
unnamed: C7.1, L3.1, U3.27
unnamed: U3.18, Y3.P$2
unnamed: U3.19, Y3.P$1
unnamed: D5.C, R13.2
unnamed: JP7.1, R11.2
unnamed: JP7.3, R12.2
unnamed: D6.A, R14.1
unnamed: D6.C, JP9.2
unnamed: C8.1, FB3.2, R15.1
unnamed: L4.2, U4.26
unnamed: C10.1, L4.1, U4.27
unnamed: U4.18, Y4.P$2
unnamed: U4.19, Y4.P$1
unnamed: D7.C, R18.2
unnamed: JP10.1, R16.2
unnamed: JP10.3, R17.2
unnamed: D8.A, R19.1
unnamed: D8.C, JP12.2
unnamed: C11.1, FB4.2, R20.1
unnamed: L5.2, U5.26
unnamed: C13.1, L5.1, U5.27
unnamed: U5.18, Y5.P$2
unnamed: U5.19, Y5.P$1
unnamed: D9.C, R23.2
unnamed: JP13.1, R21.2
unnamed: JP13.3, R22.2
unnamed: D10.A, R24.1
unnamed: D10.C, JP15.2
unnamed: C14.1, FB5.2, R25.1
unnamed: L6.2, U6.26
unnamed: C16.1, L6.1, U6.27
unnamed: U6.18, Y6.P$2
unnamed: U6.19, Y6.P$1
unnamed: D11.C, R28.2
unnamed: JP16.1, R26.2
unnamed: JP16.3, R27.2
unnamed: D12.A, R29.1
unnamed: D12.C, JP18.2
unnamed: C17.1, FB6.2, R30.1
unnamed: L7.2, U7.26
unnamed: C19.1, L7.1, U7.27
unnamed: U7.18, Y7.P$2
unnamed: U7.19, Y7.P$1
unnamed: D13.C, R33.2
unnamed: JP19.1, R31.2
unnamed: JP19.3, R32.2
unnamed: D14.A, R34.1
unnamed: D14.C, JP21.2
unnamed: C20.1, FB7.2, R35.1
unnamed: L8.2, U8.26
unnamed: C22.1, L8.1, U8.27
unnamed: U8.18, Y8.P$2
unnamed: U8.19, Y8.P$1
unnamed: D15.C, R38.2
unnamed: JP22.1, R36.2
unnamed: JP22.3, R37.2
unnamed: D16.A, R39.1
unnamed: D16.C, JP24.2
unnamed: C23.1, FB8.2, R40.1
unnamed: L9.2, U9.26
unnamed: C25.1, L9.1, U9.27
unnamed: U9.18, Y9.P$2
unnamed: U9.19, Y9.P$1
unnamed: D17.C, R43.2
unnamed: JP25.1, R41.2
unnamed: JP25.3, R42.2
unnamed: D18.A, R44.1
unnamed: D18.C, JP27.2
unnamed: C26.1, FB9.2, R45.1
unnamed: L10.2, U10.26
unnamed: C28.1, L10.1, U10.27
unnamed: U10.18, Y10.P$2
unnamed: U10.19, Y10.P$1
unnamed: D19.C, R48.2
unnamed: JP28.1, R46.2
unnamed: JP28.3, R47.2
unnamed: D20.A, R49.1
unnamed: D20.C, JP30.2
unnamed: C29.1, FB10.2, R50.1
unnamed: L11.2, U11.26
unnamed: C31.1, L11.1, U11.27
unnamed: U11.18, Y11.P$2
unnamed: U11.19, Y11.P$1
unnamed: D21.C, R53.2
unnamed: JP31.1, R51.2
unnamed: JP31.3, R52.2
unnamed: D22.A, R54.1
unnamed: D22.C, JP33.2
unnamed: C32.1, FB11.2, R55.1
unnamed: L12.2, U12.26
unnamed: C34.1, L12.1, U12.27
unnamed: U12.18, Y12.P$2
unnamed: U12.19, Y12.P$1
unnamed: D23.C, R58.2
unnamed: JP34.1, R56.2
unnamed: JP34.3, R57.2
unnamed: D24.A, R59.1
unnamed: D24.C, JP36.2
unnamed: C35.1, FB12.2, R60.1
unnamed: L13.2, U13.26
unnamed: C37.1, L13.1, U13.27
unnamed: U13.18, Y13.P$2
unnamed: U13.19, Y13.P$1
unnamed: D25.C, R63.2
unnamed: JP37.1, R61.2
unnamed: JP37.3, R62.2
unnamed: D26.A, R64.1
unnamed: D26.C, JP39.2
unnamed: C38.1, FB13.2, R65.1
unnamed: L14.2, U14.26
unnamed: C40.1, L14.1, U14.27
unnamed: U14.18, Y14.P$2
unnamed: U14.19, Y14.P$1
unnamed: D27.C, R68.2
unnamed: JP40.1, R66.2
unnamed: JP40.3, R67.2
unnamed: D28.A, R69.1
unnamed: D28.C, JP42.2
unnamed: C41.1, FB14.2, R70.1
unnamed: L15.2, U15.26
unnamed: C43.1, L15.1, U15.27
unnamed: U15.18, Y15.P$2
unnamed: U15.19, Y15.P$1
unnamed: D29.C, R73.2
unnamed: JP43.1, R71.2
unnamed: JP43.3, R72.2
unnamed: D30.A, R74.1
unnamed: D30.C, JP45.2
unnamed: C44.1, FB15.2, R75.1
unnamed: L16.2, U16.26
unnamed: C46.1, L16.1, U16.27
unnamed: U16.18, Y16.P$2
unnamed: U16.19, Y16.P$1
unnamed: D31.C, R78.2
unnamed: JP46.1, R76.2
unnamed: JP46.3, R77.2
unnamed: D32.A, R79.1
unnamed: D32.C, JP48.2
unnamed: C47.1, FB16.2, R80.1
RXI/MOSI: J3.3, U1.22
RXI/MOSI1: J7.3, U2.22
RXI/MOSI2: J11.3, U3.22
RXI/MOSI3: J15.3, U4.22
RXI/MOSI4: J19.3, U5.22
RXI/MOSI5: J23.3, U6.22
RXI/MOSI6: J27.3, U7.22
RXI/MOSI7: J31.3, U8.22
RXI/MOSI8: J35.3, U9.22
RXI/MOSI9: J39.3, U10.22
RXI/MOSI10: J43.3, U11.22
RXI/MOSI11: J47.3, U12.22
RXI/MOSI12: J51.3, U13.22
RXI/MOSI13: J55.3, U14.22
RXI/MOSI14: J59.3, U15.22
RXI/MOSI15: J63.3, U16.22
SCL/CLK: J1.4, J3.7, R4.1, U1.32
SCL/CLK1: J2.4, J7.7, R7.1, U2.32
SCL/CLK2: J9.4, J11.7, R12.1, U3.32
SCL/CLK3: J13.4, J15.7, R17.1, U4.32
SCL/CLK4: J17.4, J19.7, R22.1, U5.32
SCL/CLK5: J21.4, J23.7, R27.1, U6.32
SCL/CLK6: J25.4, J27.7, R32.1, U7.32
SCL/CLK7: J29.4, J31.7, R37.1, U8.32
SCL/CLK8: J33.4, J35.7, R42.1, U9.32
SCL/CLK9: J37.4, J39.7, R47.1, U10.32
SCL/CLK10: J41.4, J43.7, R52.1, U11.32
SCL/CLK11: J45.4, J47.7, R57.1, U12.32
SCL/CLK12: J49.4, J51.7, R62.1, U13.32
SCL/CLK13: J53.4, J55.7, R67.1, U14.32
SCL/CLK14: J57.4, J59.7, R72.1, U15.32
SCL/CLK15: J61.4, J63.7, R77.1, U16.32
SDA/CS: J1.3, J3.8, R3.1, U1.2
SDA/CS1: J2.3, J7.8, R6.1, U2.2
SDA/CS2: J9.3, J11.8, R11.1, U3.2
SDA/CS3: J13.3, J15.8, R16.1, U4.2
SDA/CS4: J17.3, J19.8, R21.1, U5.2
SDA/CS5: J21.3, J23.8, R26.1, U6.2
SDA/CS6: J25.3, J27.8, R31.1, U7.2
SDA/CS7: J29.3, J31.8, R36.1, U8.2
SDA/CS8: J33.3, J35.8, R41.1, U9.2
SDA/CS9: J37.3, J39.8, R46.1, U10.2
SDA/CS10: J41.3, J43.8, R51.1, U11.2
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

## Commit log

2019-01-18 Initial Commit
    * Adds new Eagle Part for ZOE-M8
    * Has general design layout done unless a different battery option presents itself
    * Adds datasheet for part.
    [ZOE-M8Q GPS.brd, ZOE-M8Q GPS.sch]
2019-01-22 Adds Buzzard Labels, finishes tracework (see description)
    * Moves diode and reistor
    * Fixes TSTOP on LGA
    * Moves uFL connector
    * Moves Jumpers
    [ZOE-M8Q GPS.brd, ZOE-M8Q GPS.sch]
2019-01-23 Updates silk, adds new inductor, adds LED
    [ZOE-M8Q GPS.brd, ZOE-M8Q GPS.sch]
2019-01-24 Adds pinout for FTDI connection, updates NDUC and ZOE footprints with tkeepout and tdocu, fixes silk labels
    [ZOE-M8Q GPS.brd, ZOE-M8Q GPS.sch]
2019-01-25 Adds more silk labels, adds tkeepout around oscillator and more ground vias
    [ZOE-M8Q GPS.brd]
2019-01-25 Removes one qwiic connector to make space for super capacitor, adds active antenna components (see description)
    * Adds 10 ohm resistor, ferrite bead, and 47pF capacitor.
    [ZOE-M8Q GPS.brd, ZOE-M8Q GPS.sch]
2019-01-25 Adds more ground stitching vias
    [ZOE-M8Q GPS.brd, ZOE-M8Q GPS.sch]
2019-01-26 Adds traces for unconnected ground pins, and changes 1k resistor to 100
    [ZOE-M8Q GPS.brd, ZOE-M8Q GPS.sch]
2019-01-28 Moves left standoff to be symmetrical with right, and adds measurements to standoffs
    [ZOE-M8Q GPS.brd]
2019-01-31 Adds new reflowable battery, updates battery, inductor, and IC with versions in the SparkFun Eagle Library
    [ZOE-M8Q GPS.brd, ZOE-M8Q GPS.sch]
2019-02-04 Adds more ground vias, ZOE silk to topside, adjusts safteboot trace away from RF in, adds .1uF capactior
    [ZOE-M8Q GPS.brd, ZOE-M8Q GPS.sch]
2019-02-05 Renames board files
    [SparkFun_ZOE-M8Q GPS.brd, SparkFun_ZOE-M8Q GPS.sch]
2019-02-05 Updates schematic frame to letter size, updates parts (see description)
    * Battery part updated - replaces 100 Ohm series reistor with 3.3K
    * IC part updated - better pin names on symbol
    * Inductor part updated with better pads
    * 8 Pin connector added - moves SDA and SCL to their own through hole
    * Adds and fixes silk around design
    * Adds thermals to ground pour
    [SparkFun_ZOE-M8Q GPS.brd, SparkFun_ZOE-M8Q GPS.sch]
2019-02-05 Moves Creative License text to the correct place.
    [SparkFun_ZOE-M8Q GPS.brd]
2019-02-05 Adds VCC range and i2C Address to schematic.
    [SparkFun_ZOE-M8Q GPS.sch]
2019-02-05 Adds production files and signature scorpion silk to underside of board.
    [SparkFun_ZOE-M8Q GPS.GBL, SparkFun_ZOE-M8Q GPS.GBO, SparkFun_ZOE-M8Q GPS.GBS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]
2019-02-25 Removes some silk, changes version number, removes prototype gerber files
    [SparkFun_ZOE-M8Q GPS.GBL, SparkFun_ZOE-M8Q GPS.GBO, SparkFun_ZOE-M8Q GPS.GBS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]
2019-02-26 Adds silk to battery terminals, adds initial mAH text to battery section in schematic.
    [SparkFun_ZOE-M8Q GPS.brd, SparkFun_ZOE-M8Q GPS.sch]
2019-02-26 Adds no connect silk, fixes net labels that have active low pins
    [SparkFun_ZOE-M8Q GPS.brd, SparkFun_ZOE-M8Q GPS.sch]
2019-02-26 Adds special ordering instructions and qwiic silk
    [SparkFun_ZOE-M8Q GPS.brd, SparkFun_ZOE-M8Q GPS.sch]
2019-10-14 Adds production files, removes buzzard labels
    [SparkFun_ZOE-M8Q GPS-Panel.GBL, SparkFun_ZOE-M8Q GPS-Panel.GBO, SparkFun_ZOE-M8Q GPS-Panel.GBS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]
2022-03-29 Removes note about battery capacity that is entirely made up (erroneously of course).
    [SparkFun_ZOE-M8Q GPS.sch]
2022-04-07 Updates schematic
    [SparkFun_ZOE-M8Q GPS.brd, SparkFun_ZOE-M8Q GPS.sch]

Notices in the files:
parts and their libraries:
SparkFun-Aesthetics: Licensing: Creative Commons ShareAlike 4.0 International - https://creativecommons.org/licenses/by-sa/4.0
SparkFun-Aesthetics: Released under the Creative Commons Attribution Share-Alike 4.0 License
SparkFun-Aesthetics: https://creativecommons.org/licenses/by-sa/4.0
